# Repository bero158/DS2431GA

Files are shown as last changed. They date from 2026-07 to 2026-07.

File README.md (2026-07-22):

# DS2431GA reader/programmer for Sony UP DR200 printer ribbon chip

Arduino ESP32 sketch to read, write, back up and restore the DS2431 1-Wire EEPROM used as the ID chip on Sony UP-DR200 / UP-CR20L dye-sub ribbons (and compatible generic DS2431 chips). Controlled entirely over the serial console.

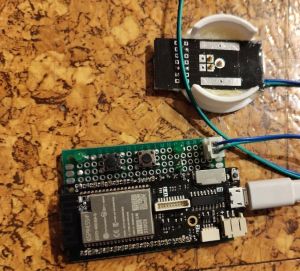
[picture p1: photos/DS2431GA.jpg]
DS2431GA project


## Features

- Detect and identify a DS2431 (or Sony custom `0xAD`) EEPROM on the 1-Wire bus
- Read the 128-byte memory as hex or plain characters
- Erase the EEPROM or write arbitrary text to it
- Read/write the protection control and user bytes (0x80-0x86)
- Parse the Sony ribbon tag (part number, serial, batch, dates, prints remaining, capacity, ...)
- Set the remaining-prints counter directly (`a` command)
- Back up EEPROM contents to a SPIFFS file, restore from it, and dump it as hex or base64
- SPIFFS file management (directory listing, delete, format) from the serial console
- Status LEDs for chip detection and write activity, plus a slow-blink watchdog LED
- Two push buttons: short/long press handling (e.g. long-press reboot). Buttons are there for further use.

## Hardware

Developed and tested on a **LOLIN D32 PRO** (ESP32).

| Signal | ESP32 default | Uno / other  |
|---|:---:|:---:|
| DS2431 1-Wire data  | GPIO 4 | A4 |
| Chip-detected LED | GPIO 13 | GPIO 13 |
| Write-activity LED  | GPIO 23 | GPIO 23 |
| Button 1 | GPIO 19 | GPIO 19 |
| Button 2 | GPIO 18 | GPIO 18 |

Connect the DS2431 data line to the configured 1-Wire pin with a pull-up resistor to 3V3 (ESP32) or 5V (Uno), and ground.

Pin numbers, button behaviour, and filesystem options are all configured in [settings.h](settings.h) — see below.

The schematics is [here](schematic/DS2431GA.png)

### Bill of materials

| Qty | Part |
|:---:|---|
| 1 | LOLIN D32 PRO (ESP32 board) |
| 2 | Low power LED |
| 2 | Resistor, 330 Ω |
| 1 | Resistor, 3k9 |
| 2 | Resistor, 1k2 |
| 2 | Universal PCB (one for the main board, one for the probe) |
| 3 | Pogo pin (for the probe) |
| 1 | JST 2-pin connector, pair (male + female) |

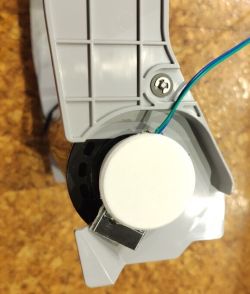
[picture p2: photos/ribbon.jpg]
Probe on a Sony DR2046 ribbon chip


## Usage

Open the Serial Monitor at **115200 baud**. In VSCode set Line Ending to CR.  On boot the sketch mounts SPIFFS and prints the menu:

```
Menu:
  EEPROM:
    e - erase memory
    h - read memory as hexadecimal
    b - backup memory to SPIFFS file
    w - recovery memory from SPIFFS file
    t - read backup as hexadecimal
    u - read backup as base64 (for download)
    s - store base64 data as SPIFFS backup file
    x - read control bytes
    c - write chars
 Sony specific:
    a - write remaining prints
    o - parse Sony ribbon tag
    p - parse backup of Sony ribbon tag
 System:
    r - reboot
    d - Directory listing of SPIFFS filesystem
    f - format SPIFFS filesystem
    k - delete SPIFFS file
    m - print menu
```
Example of the result (menu function 'o - parse Sony ribbon tag'):
```
ADDR= AD:A9:A7:51:00:10:01:C0
Device is a Sony DS custom EEPROM.

Part      : UPC-R204
Sub code  : 210
Spec date : 2011-02-25
Lot date  : 2015-12-24
Serial    : 224938000103482
Batch     : AKT441
Capacity  : 700
Remaining : 8 (1%)
Used      : 692
```

Type the letter for a command and, if prompted, follow up with the requested value terminated by Enter (Esc or Ctrl+C cancels a pending command). Commands `w`, `t`, `p`, `u`, `k`, and `s` operate on files inside `/spiffs/backup` (or `/spiffs` for `k`) and print a directory listing to help you pick a filename.

The chip-detected LED lights whenever a DS2431 is present on the bus; the write LED lights during an EEPROM write; the built-in LED blinks slowly as a watchdog heartbeat.

## Settings (`settings.h`)

| Define | Purpose |
|---|---|
| `ONE_WIRE_MAX_DEVICE` | Maximum number of 1-Wire devices expected on the bus |
| `signalPin` | 1-Wire data GPIO (GPIO 4 on ESP32, `A4` otherwise) |
| `ledChipDetectPin` | LED lit while a DS2431 is detected on the bus |
| `ledWritePin` | LED lit while writing to the EEPROM |
| `button1Pin` / `button2Pin` | GPIOs wired to the two push buttons |

Uncomment/adjust the defines to match your board and desired behaviour before building.

## Building

Open `DS2431GA.ino` in the Arduino IDE (or use `arduino-cli`) and select an ESP32 or Arduino Uno board. Required libraries:

- `OneWire`
- `jled`
- `Bounce2`
- `mbedtls` (bundled with the ESP32 core)

## Credits

Based on code originally published in the Arduino forum thread [1-Wire EEPROM DS2431GA - unlock or factory reset](https://forum.arduino.cc/t/1-wire-eeprom-ds2431ga-unlock-or-factory-reset/960298).

## License

This project is released into the public domain under [The Unlicense](LICENSE) — do whatever you want with it.

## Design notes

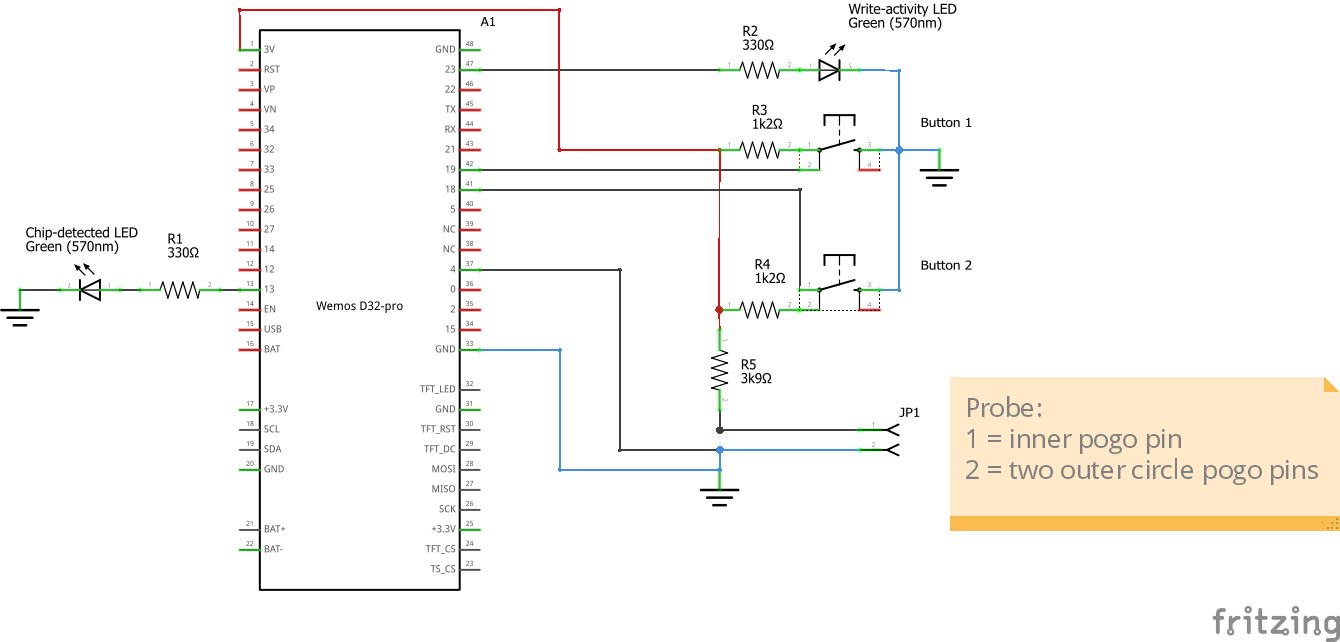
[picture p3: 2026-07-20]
schematic/DS2431GA.png

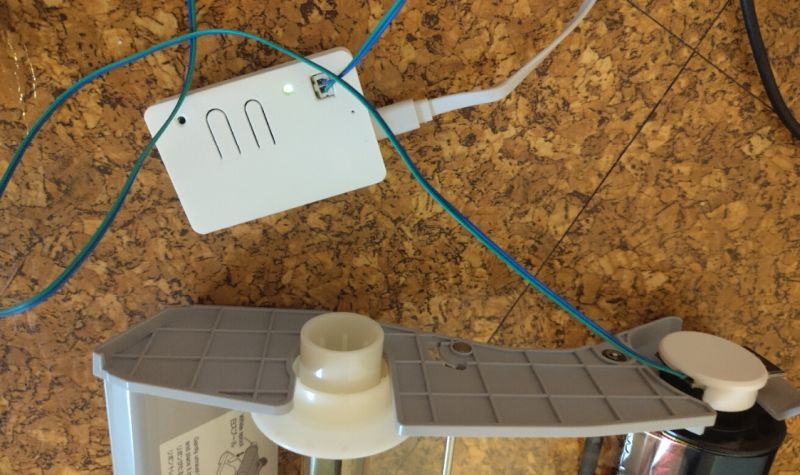
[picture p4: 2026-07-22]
photos/boxed.jpg

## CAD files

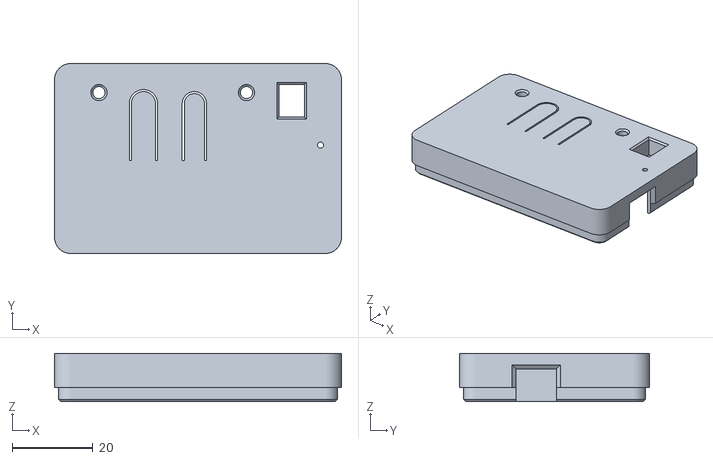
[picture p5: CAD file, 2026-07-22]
printed_parts/box/DR2046_box-Parttop.stl
71.0 x 47.0 x 11.9

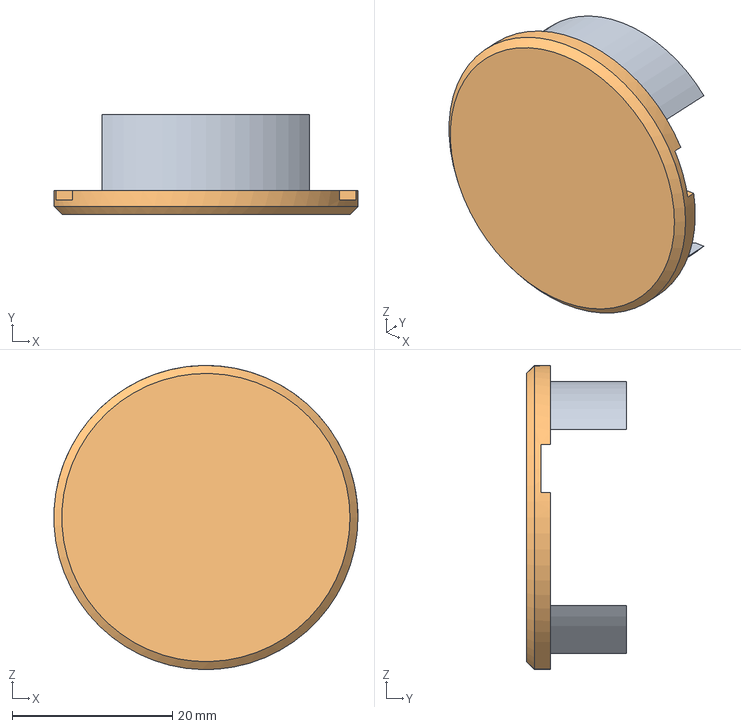
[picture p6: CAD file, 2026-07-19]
printed_parts/probe/DR2046.FCStd
38.0 x 12.5 x 38.0 mm

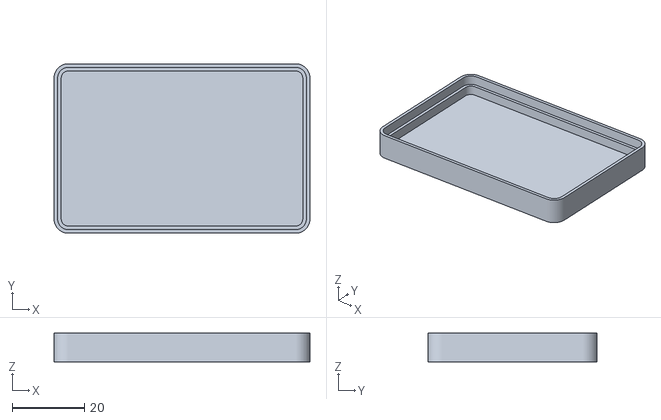
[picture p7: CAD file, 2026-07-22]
printed_parts/box/DR2046_box-Partbottom.stl
71.0 x 47.0 x 8.00

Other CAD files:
printed_parts/box/DR2046_box.FCStd
printed_parts/probe/DR2046.stl

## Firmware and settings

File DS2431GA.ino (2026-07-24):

// Arduino board configuration: works on Arduino Uno and ESP32.
// For ESP32, connect DS2431 to 3V3/GND and use a 4.7k pull-up on the data pin.
#include <Arduino.h>
#include <OneWire.h>
#include <jled.h>
#include "fs_esp_idf.h"
#include "ds2431.h"
#include "sony_ribbon.h"
#include "pushbutton.h"
#include "settings.h"
#include "version.h"
#include "system.h"
#include "cpuTimer.h"
#include <mbedtls/base64.h>
PushButton button1;
PushButton button2;
Filesystem fs;
boolean chipDetected = false;

OneWire ds(signalPin); // 1-wire on the configured data pin
byte addr[8];          // Contains the eeprom unique ID
DS2431 ds2431(ds, addr);

JLed chipDetectedLED = JLed(ledChipDetectPin);
JLed writeLED = JLed(ledWritePin);
JLed watchdogLED = JLed(LED_BUILTIN).Blink(2000, 200).Forever();
cpuTimer detectChipTimer = cpuTimer(1000, true, true); // when user clicked up/down btns show preset temp for X seconds

String printAddress(byte *address, String delimitor = ":")
{
  int i;
  String out = "";
  for (i = 0; i < 8; i++)
  {
    char buffer[3];
    sprintf(buffer, "%02X", address[i]);
    out += buffer + (i < 7 ? delimitor : "");
  }
  return out;
}

void error(boolean set, const String &message = "")
{
  Serial.println("Error: " + message);
  if (message.length() > 0)
  {
    Serial.println("Error: " + message);
  }
  if (set)
  {
    watchdogLED.Blink(200, 200).Forever();
  }
  else
  {
    watchdogLED.Blink(2000, 200).Forever();
  }
}

void setup(void)
{
  Serial.begin(115200);
  Serial.println("DS2431 EEPROM Reader/Writer ver. " + String(VERSION) + " build: " + String(BUILD_DATE));
  Serial.println("EEPROM size: " + String(DS2431_MEM_SIZE) + " bytes");
  Serial.println("1-Wire data pin: " + String(signalPin));

  button1.interval(30);
  button1.attach(button1Pin, INPUT);
  button2.interval(30);
  button2.attach(button2Pin, INPUT);

  if (!fs.mount(false))
  {
    Serial.println("Failed to mount SPIFFS filesystem");
    format();
    if (!fs.mount(false))
    {
      error(true, "Failed to mount SPIFFS filesystem");
    }
  }
  else
  {
    Serial.println("SPIFFS filesystem mounted");
  }
  fs.unmount();
  menu();
}

void dir(String root = SPIFFS_FOLDER)
{
  if (fs.mount())
  {
    Serial.println("Directory listing of SPIFFS filesystem:");
    for (const auto &entry : Dir::ls(root))
    {
      Serial.println(entry);
    }
    fs.unmount();
  }
}
void rmFile(String file)
{
  if (fs.mount())
  {
    Serial.println("Removing file: " + file);
    Dir::rm(file);
    fs.unmount();
  }
}
void menu(void)
{
  Serial.println("Menu:");
  Serial.println("  EEPROM:");
  Serial.println("    e - erase memory");
  Serial.println("    h - read memory as hexadecimal");
  Serial.println("    b - backup memory to SPIFFS file");
  Serial.println("    w - restore memory from SPIFFS file");
  Serial.println("    t - read backup as hexadecimal");
  Serial.println("    u - read backup as base64 (for download)");
  Serial.println("    s - store base64 data as SPIFFS backup file");
  Serial.println("    x - read control bytes");
  Serial.println("    c - write chars");
  Serial.println(" Sony specific:");
  Serial.println("    a - write remaining prints");
  Serial.println("    o - parse Sony ribbon tag");
  Serial.println("    p - parse backup of Sony ribbon tag");
  Serial.println(" System:");
  Serial.println("    r - reboot");
  Serial.println("    d - Directory listing of SPIFFS filesystem");
  Serial.println("    f - format SPIFFS filesystem");
  Serial.println("    k - delete SPIFFS file");
  Serial.println("    m - print menu");
  Serial.println("Press a key to select an option");
}
void backup()
{
  Serial.println("Backup ...");
  if (SearchAddress(addr))
  {
    uint8_t buffer[DS2431_MEM_SIZE];
    ds2431.ReadMemory(buffer, DS2431_MEM_SIZE);
    SonyRibbonTag tag(buffer);
    if (fs.mount())
    {
      uint16_t remaining = tag.remaining();
      String filename = String(BACKUP_FOLDER) + "/" + printAddress(addr, "") + ((remaining > 0) ? "_" + String(remaining) : "") + ".bin";
      File file(filename, "wb");
      if (file)
      {
        file.write(buffer, DS2431_MEM_SIZE);
        file.close();
        Serial.println("Backup saved to " + filename);
      }
      else
      {
        error(true, "Failed to open file for writing: " + filename);
      }
      fs.unmount();
    }
    else
    {
      error(true, "Failed to mount SPIFFS filesystem");
    }
  }
}

void loop(void)
{
  watchdogLED.Update();
  chipDetectedLED.Update();
  writeLED.Update();
  serialEvent();
  switch (button1.update())
  {

  case PushButton::press::shortpress:
    Serial.println("Button 1 short press");
    backup();
    break;
  case PushButton::press::longpress:
    Serial.println("Button 1 long press");
    for (const String &filename : Dir::ls(String(BACKUP_FOLDER) + "/*.bin"))
    {
      restore(filename);
      break;
    }
    break;
  }
  switch (button2.update())
  {
  case PushButton::press::shortpress:
    Serial.println("Button 2 short press");
    writeLED.On();
    break;
  case PushButton::press::longpress:
    Serial.println("Button 2 long press");
    break;
  }
  if (detectChipTimer.isOverTime())
  {
    if (ds2431.SearchAddress(addr))
    {
      chipDetectedLED.On();
      if (!chipDetected)
      {
        Serial.println("Detected DS2431 EEPROM with address: " + printAddress(addr));
        menu();
      }
      chipDetected = true;
    }
    else
    {
      chipDetectedLED.Off();
      chipDetected = false;
    }
  }
}

void writeString(const String &text)
{
  Serial.println("Writing chars to EEPROM ");
  byte textBytes[DS2431_MEM_SIZE];
  ds2431.stringToByteArray(text, textBytes);

  byte dat[13];
  for (int row = 0; row < 16; row++)
  { // EEPROM has 16 rows of 8 bytes
    for (int B = 0; B < 8; B++)
    { // load eight bytes at a tim6; row++){
      dat[B] = textBytes[row * DS2431_SCRATCH_SIZE + B];
    }
    Serial.print(".");
    ds2431.WriteRow(row, dat); // write the bytes out to EEPROM
    delay(100);
  }
  Serial.println("Done");
}

boolean SearchAddress(byte *address)
{ // Search for address and confirm it
  if (!ds2431.SearchAddress(address))
  {
    Serial.println("No device found.");
    return false;
  }

  Serial.println("ADDR= " + printAddress(address));

  if (OneWire::crc8(address, 7) != address[7])
  {
    error(true, "CRC is not valid, address is corrupted");
    return false;
  }

  switch (address[0])
  {
  case 0xAD:
    Serial.println("Device is a Sony DS custom EEPROM.");
    break;
  case DS2431_FAMILY_CODE:
    Serial.println("Device is a DS2431 EEPROM.");
    break;
  default:
    error(true, "Device is not a DS2431 EEPROM.");
    return false;
  }

  Serial.println();
  error(false);
  return true;
}

void printHex(const byte *data)
{
  for (int row = 0; row < DS2431_MEM_SIZE / DS2431_SCRATCH_SIZE; row++)
  { // EEPROM has 16 rows of 8 bytes
    Serial.print(row);
    if (row < 10)
    {
      Serial.print("  ");
    }
    else
    {
      Serial.print(" ");
    }
    for (int B = 0; B < DS2431_SCRATCH_SIZE; B++)
    { // load eight bytes at a time
      Serial.printf("%02X ", data[row * 8 + B]);
    }
    Serial.println();
  }
}

void ReadAllMemHex()
{
  Serial.println("Reading from EEPROM as HEX");
  ds2431.ReadStart();
  byte data[DS2431_MEM_SIZE];

  for (int i = 0; i < DS2431_MEM_SIZE; i++)

  { // EEPROM has 16 rows of 8 bytes
    data[i] = ds.read();
  }

  printHex(data);
}

void ReadProtectionAndUserBytes()
{
  Serial.println("Reading Protection Control and User Bytes (0x80-0x86):");
  byte data[7];
  ds2431.ReadProtectionAndUserBytes(data);
  Serial.printf("0x80 Page 0 protection control = 0x%02X\n", data[0]);
  Serial.printf("0x81 Page 1 protection control = 0x%02X\n", data[1]);
  Serial.printf("0x82 Page 2 protection control = 0x%02X\n", data[2]);
  Serial.printf("0x83 Page 3 protection control = 0x%02X\n", data[3]);
  Serial.printf("0x84 Factory byte (read-only) = 0x%02X\n", data[4]);
  Serial.printf("0x85 User byte 1 = 0x%02X\n", data[5]);
  Serial.printf("0x86 User byte 2 = 0x%02X\n", data[6]);
}

boolean readBackupFile(const String &filename, byte *buffer)
{
  boolean ret = false;
  String trimmed = filename;
  trimmed.trim();
  if (fs.mount())
  {
    File file(trimmed, "rb");
    if (file)
    {
      size_t bytesRead = file.read(buffer, DS2431_MEM_SIZE);
      if (bytesRead == DS2431_MEM_SIZE)
      {
        ret = true;
      }
      else
      {
        error(true, "Failed to read enough data from file: " + filename);
      }
      file.close();
    }
    else
    {
      error(true, "Failed to open file for reading: " + filename);
    }
    fs.unmount();
  }
  else
  {
    error(true, "Failed to mount SPIFFS filesystem");
  }
  return ret;
}

void restore(const String &filename)
{
  writeLED.On();
  Serial.println("Restoring from backup file: " + filename);
  if (SearchAddress(addr))
  {
    byte buffer[DS2431_MEM_SIZE];
    if (readBackupFile(filename, buffer))
    {
      ds2431.Write(buffer);
      Serial.println("Memory recovered from " + filename);
    }
  }
  writeLED.Off();
}
void readFileHex(const String &filename)
{
  byte buffer[DS2431_MEM_SIZE];
  if (readBackupFile(filename, buffer))
  {
    printHex(buffer);
  }
}
void writeFileBase64(const String &filename, const String &base64Data)
{
  byte buffer[DS2431_MEM_SIZE];
  size_t olen;
  int ret = mbedtls_base64_decode(buffer, sizeof(buffer), &olen, (const unsigned char *)base64Data.c_str(), base64Data.length());
  if (ret != 0)
  {
    Serial.println("Failed to decode base64 data");
    return;
  }
  if (olen != DS2431_MEM_SIZE)
  {
    Serial.println("Decoded data size does not match expected EEPROM size");
    return;
  }

  if (fs.mount())
  {
    File file(filename, "wb");
    if (file)
    {
      file.write(buffer, DS2431_MEM_SIZE);
      file.close();
      Serial.println("Base64 data written to " + filename);
    }
    else
    {
      Serial.println("Failed to open file for writing: " + filename);
    }
    fs.unmount();
  }
  else
  {
    Serial.println("Failed to mount SPIFFS filesystem");
  }
}
void readFileBase64(const String &filename)
{
  byte buffer[DS2431_MEM_SIZE];
  if (readBackupFile(filename, buffer))
  {
    char encoded[DS2431_MEM_SIZE * 2]; // Base64 encoded size
    size_t olen;
    mbedtls_base64_encode((unsigned char *)encoded, sizeof(encoded), &olen, buffer, DS2431_MEM_SIZE);
    Serial.println(encoded);
  }
}

void erase()
{
  Serial.print("Writing zeros EEPROM ");
  ds2431.Erase();
  Serial.println("Done");
}

/*
  SerialEvent occurs whenever a new data comes in the
 hardware serial RX.  This routine is run between each
 time loop() runs, so using delay inside loop can delay
 response.  Multiple bytes of data may be available.
 */
byte command = 0;
String inputBuffer; // Buffer to hold incoming data

void clearCommand()
{
  command = 0;
  inputBuffer = ""; // Clear the buffer
}
void serialEvent()
{
  byte inChar;
  String filename = "";
  while (Serial.available())
  {
    // get the new byte:
    inChar = (byte)Serial.read();
    if (command)
    {
      if ((inChar == '\n' || inChar == '\r') && inputBuffer.length() == 0)
      {
        // ignore empty lines
        continue;
      }
      if (inChar == 27 || inChar == 0x3)
      { // ESC key, Ctrl+C
        Serial.println("Command cancelled.");
        clearCommand();
        return;
      }
      if (inChar == '\n' || inChar == '\r')
      {
        // end of input, process the command
        switch (command)
        {
        case 'a':

          int copies;
          copies = inputBuffer.toInt();
          if (copies <= 0 || copies > 700)
          {
            Serial.println("Invalid number of copies. Please enter a positive integer less than or equal to 700.");
            return;
          }
          Serial.println("Writing " + String(copies) + " remaining prints to EEPROM");
          writeRemaining(copies);
          break;

        case 'c':
          if (SearchAddress(addr))
          {
            writeLED.On();
            writeString(inputBuffer);
            writeLED.Off();
          }
          break;
        case 'w':
          filename = String(BACKUP_FOLDER) + "/" + inputBuffer;
          restore(filename);
          break;
        case 't':
          filename = String(BACKUP_FOLDER) + "/" + inputBuffer;
          readFileHex(filename);
          break;
        case 'p':
          filename = String(BACKUP_FOLDER) + "/" + inputBuffer;
          byte buffer[DS2431_MEM_SIZE];
          readBackupFile(filename, buffer);
          parseBuffer(buffer);
          break;
        case 'u':
          filename = String(BACKUP_FOLDER) + "/" + inputBuffer;
          readFileBase64(filename);
          break;
        case 'k':
          filename = String(SPIFFS_FOLDER) + "/" + inputBuffer;
          rmFile(filename);
          break;
        case 's':
          // separate filename and base64 data by space
          int spaceIndex = inputBuffer.indexOf(' ');
          if (spaceIndex != -1)
          {
            filename = String(BACKUP_FOLDER) + "/" + inputBuffer.substring(0, spaceIndex);
            String base64Data = inputBuffer.substring(spaceIndex + 1);
            writeFileBase64(filename, base64Data);
          }
          else
          {
            Serial.println("Invalid input. Please provide filename followed by base64 data separated by space.");
          }
          break;
        }
        clearCommand();
      }
      else
      {
        inputBuffer += (char)inChar; // append to input buffer
      }
    }
    else
    {
      switch (inChar)
      {
      case 'e':
        if (SearchAddress(addr))
        {
          writeLED.On();
          erase();
          writeLED.Off();
        }
        break;

      case 'h':
        if (SearchAddress(addr))
        {
          ReadAllMemHex();
        }
        break;

      case 'x':
        if (SearchAddress(addr))
        {
          ReadProtectionAndUserBytes();
        }
        break;

      case 'b':
        backup();
        break;

      case 's':
        command = 's';
        Serial.println("Enter filename followed by base64 data separated by space to write SPIFFS backup file:");
        break;
      case 'd':
        dir();
        break;

      case 'c':
        command = 'c';
        Serial.println("Enter string to write to EEPROM (max 128 chars):");
        break;
      case 'w':
        command = 'w';
        Serial.println("Enter filename to recover memory from SPIFFS file:");
        dir(BACKUP_FOLDER);
        break;
      case 't':
        command = 't';
        Serial.println("Enter filename to read backup as hexadecimal from SPIFFS file:");
        dir(BACKUP_FOLDER);
        break;
      case 'p':
        command = 'p';
        Serial.println("Enter filename to parse backup of Sony ribbon tag from SPIFFS file:");
        dir(BACKUP_FOLDER);
        break;
      case 'u':
        command = 'u';
        Serial.println("Enter filename to read backup as base64 from SPIFFS file:");
        dir(BACKUP_FOLDER);
        break;
      case 'k':
        command = 'k';
        Serial.println("Enter filename to delete from SPIFFS:");
        dir();
        break;

      case 'm':
        menu();
        break;

      case 'o':
        parse();
        break;
      case 'r':
        systemFNC::restart("User requested reboot");
        break;

      case 'a':
        command = 'a';
        Serial.println("How many copies?");
        break;
      case 'f':
        format();
        break;
      }
    }
  }
}

void format()
{
  writeLED.On();

  Serial.println("Formatting SPIFFS filesystem...");
  if (fs.format())
  {
    Dir::md(SPIFFS_FOLDER);
    Dir::md(BACKUP_FOLDER);
    Serial.println("SPIFFS filesystem formatted successfully.");
  }
  else
  {
    error(true, "Failed to format SPIFFS filesystem.");
  }
  writeLED.Off();
}
void parseBuffer(byte *buffer)
{
  SonyRibbonTag tag(buffer);
  Serial.println(tag.toString());
}

void parse()
{
  if (SearchAddress(addr))
  {
    uint8_t buffer[DS2431_MEM_SIZE];
    ds2431.ReadMemory(buffer, DS2431_MEM_SIZE);
    parseBuffer(buffer);
  }
}

void writeRemaining(uint16_t remaining)
{
  if (SearchAddress(addr))
  {
    writeLED.On();
    uint8_t buffer[DS2431_MEM_SIZE];
    ds2431.ReadMemory(buffer, DS2431_MEM_SIZE);
    SonyRibbonTag tag(buffer);
    uint8_t row, count;
    tag.remainingW(remaining, &row, &count);
    for (uint8_t r = row; r < row + count; r++)
    {
      uint8_t rowData[8];
      tag.rowData(r, rowData);
      ds2431.WriteRow(r, rowData);
    }
    writeLED.Off();
  }
}

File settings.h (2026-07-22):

#pragma once

//#define _DEBUG //log debug info
#define ENABLE_OTA //OTA allowed

#define ONE_WIRE_MAX_DEVICE 1 //max count. of Dallas devices

#define SPIFFS_FOLDER "/spiffs"
#define BACKUP_FOLDER "/spiffs/backup"

//Pins definition
#if defined(ARDUINO_ARCH_ESP32)
    const int signalPin = 4; // 1-Wire data GPIO on ESP32
#else
    const int signalPin = A4;
#endif
const int ledChipDetectPin = 13;  // Use a non-strapping GPIO for stable boot/upload
const int ledWritePin = 23; // LED to indicate writing to EEPROM
const int button1Pin = 19; // Button to trigger reading EEPROM
const int button2Pin = 18; // Button to trigger writing EEPROM

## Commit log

2026-07-19 new file: .gitignore new file: DS2431GA.ino new file: LICENSE new file: README.md new file: cputimer.h new file: ds2431.cpp new file: ds2431.h new file: fs_esp_idf.cpp new file: fs_esp_idf.h new file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
    [DR2046.FCStd, DR2046.stl]
2026-07-20 Update README with schematics link
    Added a note about schematics location in README.
2026-07-20 Update project description for printer ribbon chip
2026-07-22 modified: DS2431GA.ino modified: README.md new file: photos/boxed.jpg new file: printed_parts/box/DR2046_box-Partbottom.stl new file: printed_parts/box/DR2046_box-Parttop.stl new file: printed_parts/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
    [DR2046_box-Partbottom.stl, DR2046_box-Parttop.stl, DR2046_box.FCStd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]
